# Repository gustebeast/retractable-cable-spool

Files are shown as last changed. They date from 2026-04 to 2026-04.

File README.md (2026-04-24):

# Retractable Cable Spool

A 3D-printable retractable cable spool driven by a constant-force spring, with a
ratchet to hold the cable out and a brake to control speed while retracting.

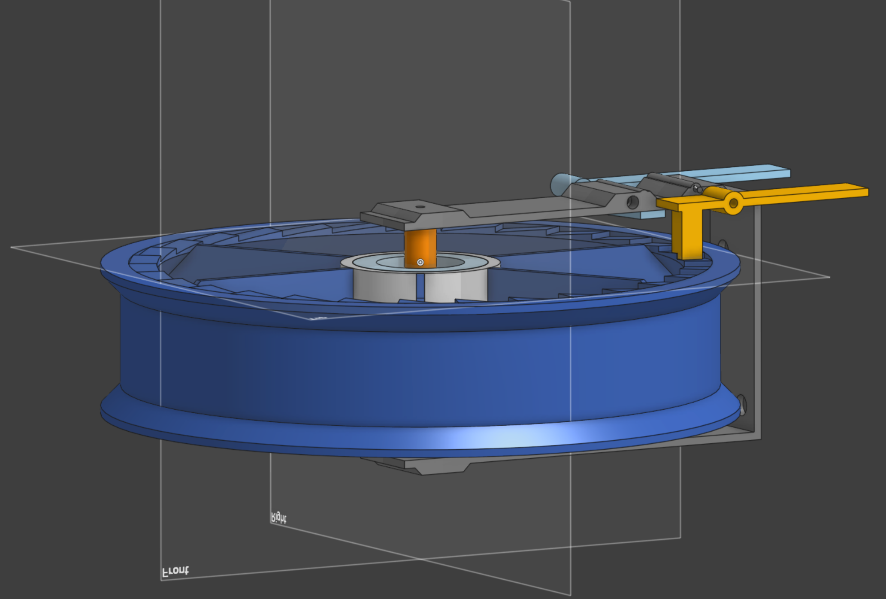
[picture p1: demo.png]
Assembly preview


## Source

All geometry lives in [`spool_flange.py`](spool_flange.py) — a single
[cadquery](https://cadquery.readthedocs.io/) script that generates every
printed part and the full assembly. The script was written collaboratively
with an LLM (Claude), which also handled the geometry math, the sourcing
research, and the assembly/printing documentation embedded in the module
docstring.

## Building

```bash
py -3.12 -m pip install cadquery
py -3.12 spool_flange.py
```

Running the script regenerates every STEP file in this directory:

- `spool_main_body.step` — spool with drum, flanges, ratchet teeth, brake ring
- `bearing_cap.step` — top bearing retainer
- `axle.step` — fixed center shaft with integrated spring stub
- `lever_housing.step` — U-bracket carrying both levers above the top flange
- `ratchet_lever.step`, `brake_lever.step` — the two actuating levers
- `brake_housing_pin.step` — small separately-printed stop pin (glues into the housing)
- `ratchet_spring.step`, `brake_spring.step` — visualization-only dummies of the purchased torsion springs
- `assembly.step` — everything in its as-built relative position, for dimensional verification

## Documentation

Everything you need to build one — purchased parts with SKUs and links,
sourcing plan, tuning constants, print orientation, and step-by-step
assembly — is in the module docstring at the top of
[`spool_flange.py`](spool_flange.py).

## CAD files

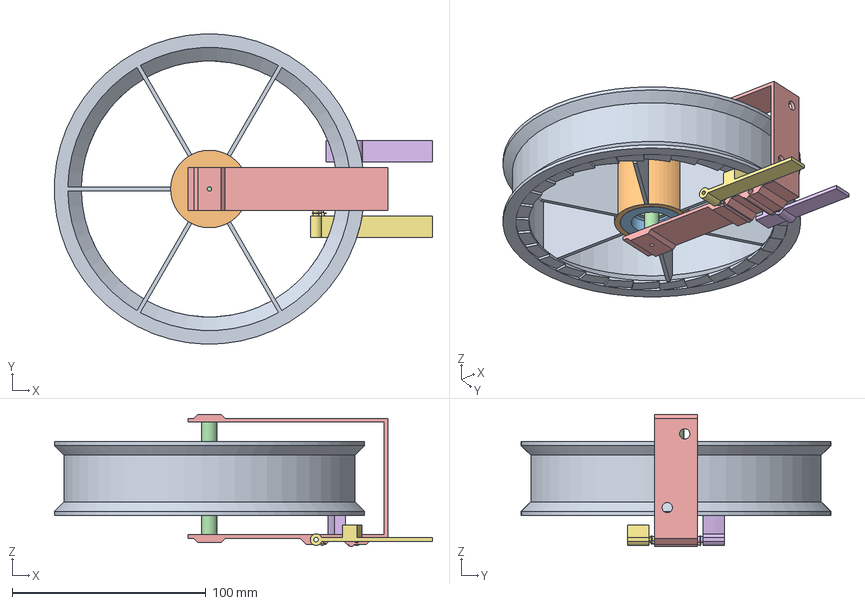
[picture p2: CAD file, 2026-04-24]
assembly.step
194.9 x 159.9 x 68.1 mm
main_body
bearing_cap
axle
lever_housing
ratchet_lever
brake_lever
ratchet_spring
brake_spring
brake_housing_pin

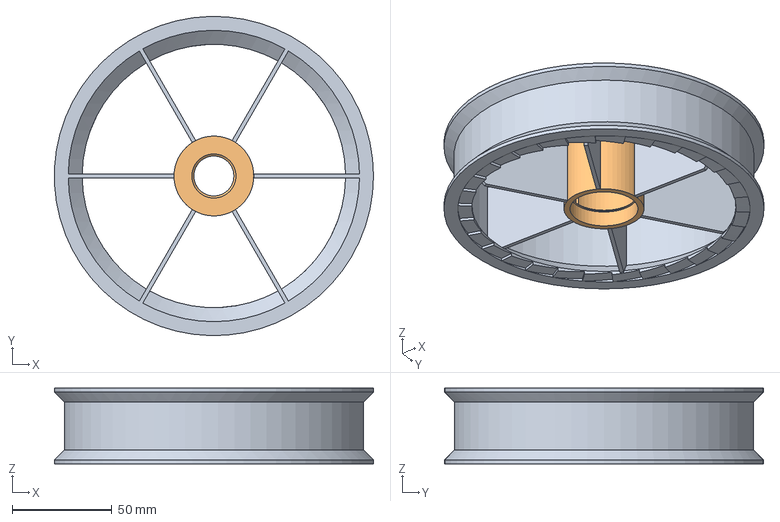
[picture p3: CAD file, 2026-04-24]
spool_main_body.step
159.9 x 159.9 x 38.0 mm

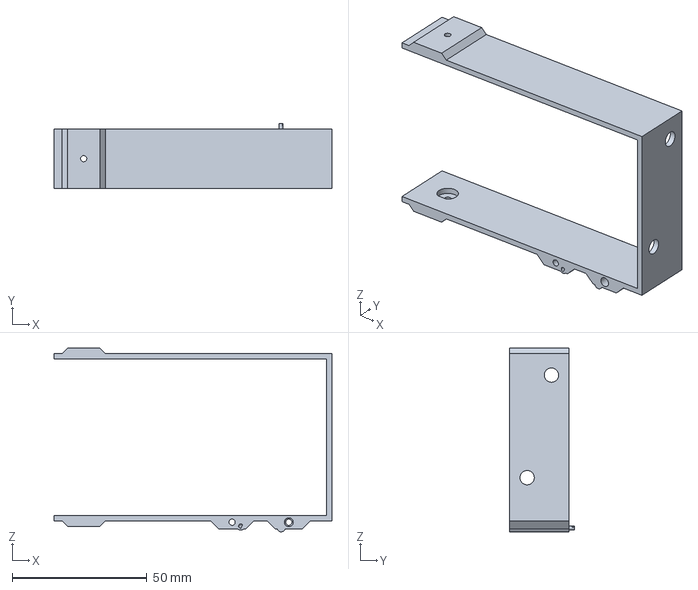
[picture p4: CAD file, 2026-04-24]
lever_housing.step
103.0 x 24.0 x 68.1 mm

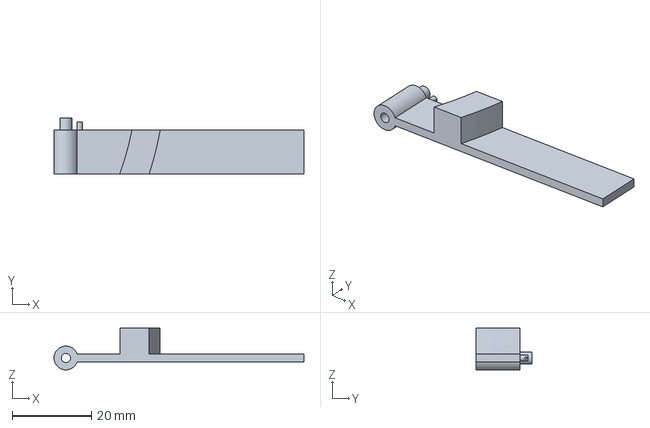
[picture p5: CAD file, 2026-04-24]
brake_lever.step
63.0 x 14.0 x 10.5 mm

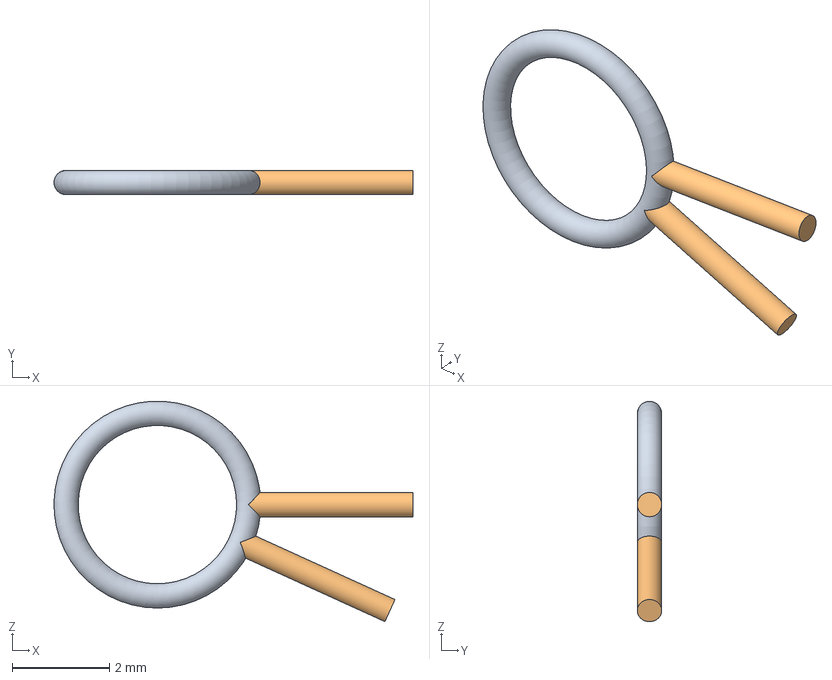
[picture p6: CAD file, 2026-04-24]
brake_spring.step
7.37 x 0.5 x 4.53 mm

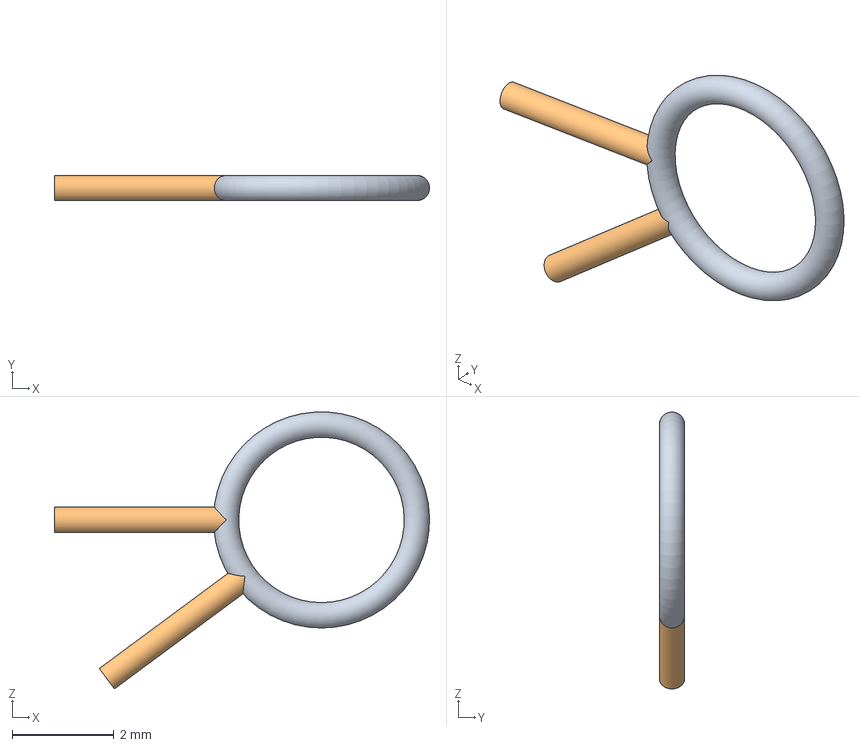
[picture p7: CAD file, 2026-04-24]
ratchet_spring.step
7.37 x 0.5 x 5.44 mm

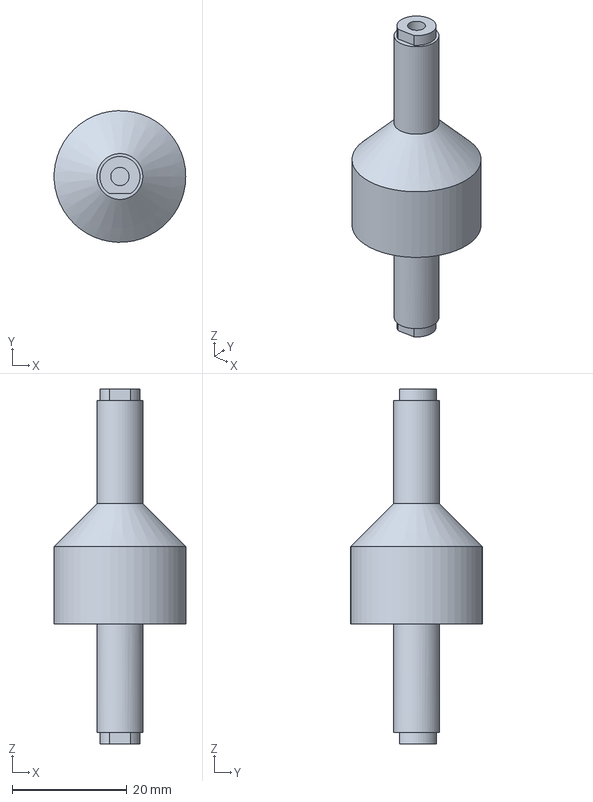
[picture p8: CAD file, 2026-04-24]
axle.step
23.0 x 23.0 x 62.0 mm

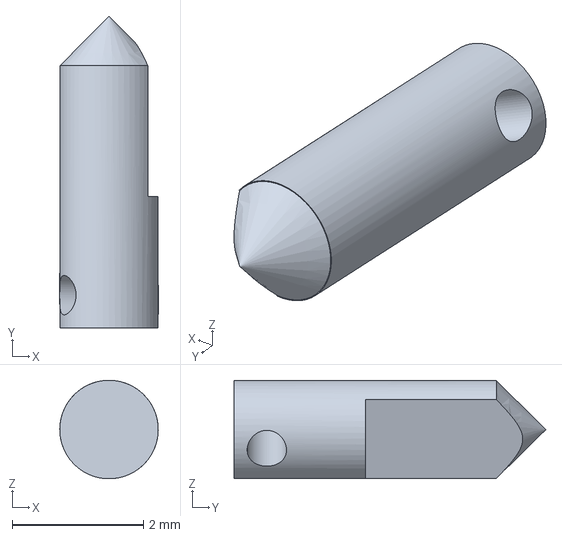
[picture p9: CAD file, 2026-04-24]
brake_housing_pin.step
1.50 x 4.75 x 1.50 mm

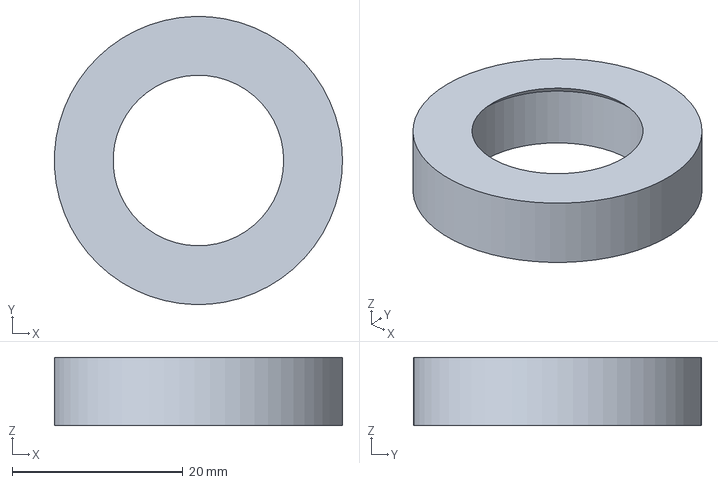
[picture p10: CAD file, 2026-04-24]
bearing_cap.step
33.8 x 33.8 x 8.00 mm

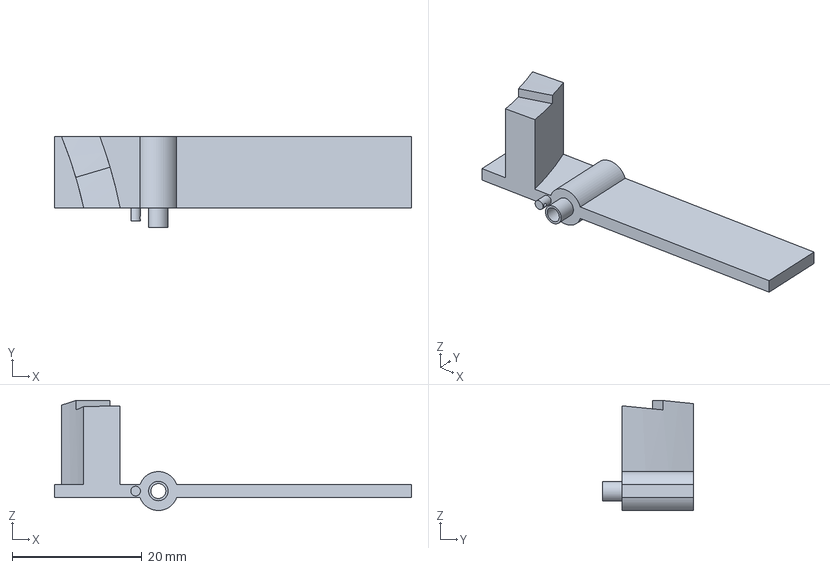
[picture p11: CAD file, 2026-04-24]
ratchet_lever.step
55.0 x 14.0 x 16.9 mm

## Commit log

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2026-04-25 Add source-cable pancake spool, wrap-around housing, and split bearing caps
    Major redesign to support a USB-C source cable that trades wraps with the
    main drum: pulling the retractable cable out unwinds the main drum and
    winds the source cable onto a small "pancake" spool integrated into the
    top bearing cap, so a single continuous cable runs from the wall outlet
    through the housing back panel, around the pancake, down through the
    spool interior, and out the drum OD — no slip ring required.
    Geometry changes:
    - Split bearing_cap into bearing_cap_top (with pancake spool) and
    bearing_cap_bottom (plain). Bearings now press in from the
    hub-cavity (interior) face of each cap.
    - 90° flat ret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
2026-05-07 Reorganize into src/, beef up housing, add cable transit through cap
    Major changes since the original monolithic spool_flange.py:
    - Modularize: split the build script into per-part modules under src/
    (dimensions, helpers, spool, caps, axle, housing, housing_guide,
    housing_pins, guide_axle, levers, viz, build). Cross-cutting concerns
    (cap key grooves, lever-dependent ratchet teeth, guide-bearing area)
    exposed as pure apply_to_*() functions called by build.py. Add a CLI
    --part NAME / --list to build a single part.
    - Geometry regression check: tools/check_geometry.py + tools/baseline.tsv
    detect accidental dimensional drift across refactors.
    - Structural beef-up: housing top/botto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
2026-05-07 Open-bottom-axle redesign: lever-side guide bearing + pancake removed
    - Eliminate pancake spool; source cable exits at lever-side axle bottom
    - Add lever-side 608 guide bearing between levers (rides on brake track)
    - Move RATCHET_PIVOT_X 76->70 to clear new bearing footprint
    - Move BRAKE_PIVOT_X 55->62 to preserve matched ROM ratio
    - Asymmetric housing trim: lever-side x_min=57, pancake-side x_min=-6
    - Remove back spine and lever-side cross-pin (no plate at x=0)
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2026-05-12 Drum: apply constant-thickness relief LAST, fixing the lost transit slot
    The groove-following relief leaves valid-but-fragile geometry that OCCT
    silently no-ops downstream booleans on (the cable-transit slot cut was
    vanishing, non-deterministically). Restructure: spool.py hands off the
    drum with the full-thickness wall (+cradle cut only); cap/lever cuts run
    on that robust geometry; build.py applies the relief last, after which
    nothing cuts main_body but the final heal. Lever cuts now remove the
    expected ~3164 mm^3 (was ~137 when the slot no-op'd).
    Also: spokes reach the cradle-bottom radius so they land flush on the
    relieved wall at each cradle crossing. Back guide axle TEMP at 2x length
    (u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
2026-05-12 Revert back guide axle to normal length (was 2x for update verification)
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2026-05-19 Checkpoint before lever pivot restructure (build #103)
    Captures current state of housing, levers, mount bracket, axle changes,
    and housing pin slab geometry before moving RATCHET_PIVOT_X and
    BRAKE_PIVOT_X to satisfy matched-ROM and pawl-clearance assertions.
2026-05-23 Checkpoint: remove guide axle/bearing + guide wheels (build #195)
    The -X housing extension is now a plain rectangular prism (no bearing
    pocket, no house-shape/M2 cut). Both guide wheels and the back-axle
    guide assembly are gone from the build, PARTS dict, assembly, and viz.
    Green at build #195. Checkpoint before the lever 90-degree rework
    (axial -> radial engagement, housing U -> L).
2026-05-23 Radial lever rework: L-housing, 90-deg levers, kinematic assertions (build #198)
    Levers rotated 90 deg to engage the rim's outer cylindrical bands radially:
    - Housing U -> L: vertical front-housing block on +X (carries both Y-axis
    M2 pivot screws) + pancake plate + plain -X extension. Front housing
    re-anchored to RIM_OD/2 + 5 mm (old SPOOL_CLEARANCE), not the stale
    FLANGE_OD.
    - Ratchet pivot above the teeth (z=17), brake pivot below the band (z=-3.5);
    both handles hang down and pull +x. Ratchet rest=engaged, brake rest=
    disengaged. Contacts are arc-conforming (pawl in the valley, pad on the
    band) with a viz rubber slab.
    - lever_kinematics.py rebuilt for radial engagement with loa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
2026-05-24 Polish radial levers + housing flush-mount/spring fixes (build #206)
    Lever shape/function:
    - Ratchet pawl now meshes with the actual rim teeth (carved with the rim
    ratchet band +/- backlash) instead of a smooth arc that fouled the tips —
    a true one-way catch (locks unwind, clicks the other way).
    - Handles are tapered rounded paddles (grip) instead of straight bars.
    - Rest-pose print-warp precomp set to 0 (radial levers print flat).
    Band swap + kinematics:
    - Swapped rims: ratchet teeth on the bottom (z=0..7), brake band on top
    (z=7..14), so the brake pivot lands ABOVE the spool bottom. Both pivots
    positive (ratchet 10, brake 3.5); lever hang -38 -> -19.
    - Kinematic assertions hold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
2026-06-11 Bands doubled (6mm ratchet + 6mm wheel), brake rim 11.6mm, pivot rework (build #484)
    - RATCHET_BAND_H 3->6 (teeth were skipping), pawl bump catch-face contact
    - Guide wheels 6mm tall; RATCHET_PIVOT_Z derived up to 16.1 to clear them
    - Brake band sized from pad needs (9 + 1 + 1.6 = 11.6mm), RIM_H 19.1
    - BRAKE_CONTACT_DELAY_DEG=3 handoff delay, pad rest gap 0.69 -> 1.72mm
    - M2 head recess in levers (spacers removed), 2.2mm self-tap bores in housing
    - Lever-housing gap 4.5 -> 3.3 (0.4mm spring spacers), pins auto-centered holes
    - Cable entry tunnel walled channel + z-cap, spring screw access hole
    - Spoke branching 48->24->12 (twist-extrude, ~45% material saving)
    - Retainer radial gap 2.5 -> 1.0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
2026-07-30 Commit to the modular redesign: promote v2/ to src/, delete v1
    The from-scratch modular design (spring-housing backbone + sliding
    stack) is THE spool now:
    - v2/*.py moved into src/; build is `py -3.12 -m src.build`, part STEPs
    export as src/<part>.step (no prefix), root viewer STEP unchanged.
    - v1 modules and archive/ deleted - git history is the reference. The
    four legacy modules the design still consumes survive: helpers,
    dimensions, caps, and axle_base (renamed from axle.py; the current
    axle extends its proven halves).
    - Every v1/v2 mention scrubbed from names, parts, outputs and comments.
    - Session work included: 2.4 ratchet teeth, GF depth-face joint
    clearances + quality hook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
2026-08-04 v3 axial redesign: rotating axle on a frame-pocketed 608, twist-lock spring anchor
    Archive the v2 modular design to v2/ and rebuild src/ around axial cable
    storage: the 608 sits IN the top frame and the axle rotates (spring
    arbor), separator fused to the bottom axle half, flat-spiral drum + lid
    on a rotational bayonet, fused bottom frame with spoked floor and center
    guide sleeve, bottom-608 spindle seat, ported v2 levers with the full
    kinematics assertion suite, and the spring strip now anchoring by a
    twist-lock window (teardrop neck hole + 45 degree insertion slot, no
    extra parts) in a wall under the +X arm. Build #837, overlap gate clean.
2026-08-04 Anchor window rework: tension-trap tent replaces the twist-lock cuts
    The teardrop+45-slot window still left an overhang at the slot's upper
    end cap (user catch). New shape per user's design: a tent window - flat
    top, 12-high side bays, 45 degree V floor to an 18.4 peak. The head
    enters flat-on at the tall middle (no twist), and the spring's
    one-signed tension parks the strip in a side bay too short for the head
    to escape. Symmetric so either spring handedness works. Every opening
    edge is vertical, 45 degrees, or a print floor. Build #838, gate clean.
2026-08-04 Bias the anchor window to the pinned spring chirality
    User pinned the rotation sense: pull-out spins the axle CW and tightens
    the spring, so the strip runs CCW going outward and its tension drags
    the anchored end toward -y. The symmetric tent becomes the original
    single-sided trapezoid: tall entry wall at +y (18.4 - head enters
    flat-on), one 45-degree floor climbing to the -y holding bay (12).
    Width forced at 6.4 by the 45-degree climb. Build #839, gate clean.
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2026-08-04 Flip frame_top upright: funnel bearing seat, mirrored window, flat-top joints
    frame_top now prints -z to +z (user's call), which reshapes everything
    orientation-dependent on it: the bearing seat becomes a 45-degree
    funnel cone (the flat lip step would overhang; the outer race chamfer
    lands face-on-face, 0.1 deep like the bottom seat); the anchor window
    z-mirrors (45-degree roof up to a dulled tip, stepped free bottom with
    a raised bay floor guarding the rotating lid below); and the anchor
    wall thickens to 2.4 by taking 0.8 from the flange clearance, outer
    face unmoved. The arc joints drop the arrowhead's angled top for a
    FLAT-TOP profile (both hosts print it fine now), and the separator/lid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
2026-08-04 Restore the +z-to--z window shape; funnel seat and flat-top joints stand
    Misread the flip: frame_top prints +z to -z (top face on the bed). The
    window returns to the #840 trapezoid - flat +z edge (prints as a
    floor), 45-degree floor down to the dulled one-bead tip (the roof of
    the hole as printed) - keeping the 2.4 wall on the 1.0 flange
    clearance. The funnel bearing seat is orientation-correct here too (a
    45-degree narrowing taper, upgrading the old accepted bridge-ring),
    and the flat-top arc joints + swapped sep/lid bayonet stand as-is:
    frame_top's cavities open at the print top with plain floors.
    Build #842, gate clean.
2026-08-04 Flush desk mount + per-side lever fork roofs
    MOUNT (v3 redesign, v2's validated wood screw verbatim): two identical
    brackets ride the +-Y arms - the rotating axle caps the centre so no
    full-length bar can cross flush, and flush is the point: assembled, the
    bracket tops sit level with the frame top face and the stack stays 10.4
    thick. Each bracket = mushroom tenon (new cadkit THROUGH-mortise site,
    both hosts print +z to -z) under a flush spine one stem wide, a shallow
    rail crossing the arc-joint zone in a 45-degree-V groove, and a screw
    pad in free air outboard of the arm tip. Both arms seat on one frame +y
    slide (cable pull preloads the seat; no lock insert, user's call);
    removal slides back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
2026-08-04 Close the wall band's bottom rim across the lever bays
    User catch (miscommunication resolved - wall_top's #834 C-ring stands):
    the bays' floor-up cut severed the fused band's bottom rim AND left the
    axial coil chamber open at both bays. The bay windows now start at the
    chamber ceiling (CH_TOP_Z): below it the band runs a closed ring again
    - bottom rim + coil containment - and every lever working part crosses
    the wall above it. Build #844, gate clean; posed probes (ratchet at the
    20-degree travel limit, brake + pad at contact) all 0.0000 against the
    restored band.
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2026-08-05 Mount rework: one-piece flush twist-lock ring
    Per the user's design review: the mount is now ONE continuous ring (no
    spacing error possible), its screws sit on quadrant pads INSIDE the
    frame footprint, and install is screw-first then offer-up + rotate ~9
    degrees to the stops - the same motion and angular constants as the
    frame_top<->frame_bottom arc joints. Rotation is what makes the
    one-piece geometry possible at all: the ring maps onto its own circle
    during install, so nothing sweeps across the axle. The ring sits at
    r 71.2 - the farthest bead radius out the arms whose THROUGH cavities
    keep a 1.6+ web to the frame arc joints (user: joinery near the beam
    ends, but clear of the top<->bottom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
2026-08-05 45-degree hand ports through the fork-side blocks at both bays
    User: the web/column corner still pinched hand access to the levers.
    Each bay gets a port cut through the web + column + pad along Y: inner
    edge ON the wall bottom's OD (user's datum), vertical sides, and a
    single-pitch 45-degree roof rising toward the wall - printable upright.
    The column keeps a full-height foot leg outboard of the port and the
    web's wall-continuation inboard of the OD is untouched. Per-side eaves:
    ratchet to the chamber ceiling; brake stops 0.8 under its low pivot
    boss, with the roof-tangent (R*sqrt2) term since a 45-degree roof binds
    at the circle's tangent point, not its bottom. Build #849, gate clean.
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2026-08-05 Mount refinement: pads are the stop, 51% arm intact, full-depth tenons
    Three user passes: (1) screw pads at ZERO gap - seated, each pad lands
    flat on its arm's flank, making the pads the seating stop; the arc
    joints keep their 0.15 seat clearance and never bottom (pad azimuth
    now derived exactly, screws +-10.65 off-axis - the beam just needs to
    span both screws of a pair). (2) joint width 6.4 -> 4.8: the cavities
    now leave 51% of the arm's width intact (asserted >= 49%). (3) tenons
    grown to fill the through cavities (cadkit tenon_arc height override,
    canonical synced): tips one bead above the arms' undersides, hovering
    over the spring-flange plane at the inner ring. Build #858, gate
    clean; p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
2026-08-05 Mount joint trimmed from the stop side: 50/50 tenon vs arm
    User: the tenon should fill its mortise, and the mortise should take
    no more of the arm than needed - reduce from the stop side. The tenon
    now ANCHORS AT THE ARM'S ENTRY FACE and spans MOUNT_TEN_ARC = half the
    crossing (5.2 arc-mm) inboard; the cavity is exactly tenon + seat +
    entry overshoot, so the stop-side HALF of every crossing is solid arm
    (5.1mm, was a 1.6 stop wall). Install twist drops to ~11.1 deg.
    Build #861, gate clean; probes: engaged 5.2 / solid 5.1 per crossing
    on both rings, frame_top intersect 0.0000 across the rotation.
2026-08-05 Frame arc joints adopt the mount rings 50/50 scheme
    User: copy the mount joint's clearance figures to the bottom<->top
    frame joint. The frame arc tenons now anchor at their arm's entry face
    and span half the crossing; the cavities are exactly tenon + seat +
    entry overshoot, leaving the stop-side half of each arm crossing solid
    (TOP_STOP_WALL retired - the stop wall is wherever the cavity ends).
    Build #862, gate clean; probes: seated 0.0000, install path clear
    through -25 deg, stop direction binds immediately as designed.
2026-08-05 Revert the frame arc-joint 50/50 change (user: misunderstanding) - frame_top/frame_bottom joints back to centered tenons + TOP_STOP_WALL; mount rings keep their #861 scheme. Rebuilt as #862, gate cle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
2026-08-05 Mount joint gets the frame joints depth-face clearance; frame arc tenons run flush to the entry face - (1) user: copy the z-clearance figures from frame_top/frame_bottom to frame_top/mount: the mushr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
2026-08-05 Open exit-port top; octagon Z-relief on mount joint; 50 percent rule + shared cadkit crossing for both ring joints [build 866]
    Wall: the exit-port sawtooth ceiling is retired (user: unnecessary overhang) - the port cuts open through the band top rim over its ~30 deg span; CABLE_EXIT_TEETH and its assert removed.
    Mount joint: cadkit octagon now carries the 0.30 z-relief via the user mechanism (mortise waist vertical +0.30, tenon stem +0.30 - the stop sign rides down to fill it), so separating frame from mount rides 0.30 before the flare faces engage. Arm floor under the deeper cavities: 1.63 (>= 1.6 asserted).
    Frame joint: the 50 percent rule applies here after all (user reversed the earlie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
2026-08-05 Flip both rotational joints so sustained loads preload the stops [build 867]
    Chirality audit (user worry: rotational joinery working undone over time). With the as-built hand, every sustained load pointed at the ENTRY: parked, the spring torque loop reacts CW on frame_top (strip anchor at +X pulled -Y) and CCW on frame_bottom (ratchet pawl holding the separator) - the unseating relative twist across the frame joint; pull-out torques the whole assembly CW (cable line of action is tangent on the drum CW-driving side) - the mount joint uninstall direction; retraction brake drag matched.
    Fix: cadkit ArcCrossing gained a hand parameter (canonical d4f4923); both crossings flipped to hand=ccw. fra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
2026-08-05 Open-ended axle slits (slide onto the fixed strip) + fix the open-shell artifact Bambu flagged [build 873]
    Axle slits: the closed-window design assumed the spring strip could thread through - it cannot (the strip is fixed). Reverted to v2: each half slit is fully open at its joint-side end and the halves slide onto the strip - separator open through its +z column top (mortise mouth splits into two C-halves), axle_top open through its tenon bottom. The strip starts 4mm in from the spring edges (user), so the closed ends land just past the strip zone: STRIP_Z0/Z1 = spring edges -/+ 4, SLIT_Z_CLR 1.0. axle_top keeps a solid shaft above the strip zone (through the bearing); the separator keeps s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
2026-08-05 Tenon tip lands at the strip start - 4 (not 5) above the spring bottom [build 874]
    User catch: axle_top ended 5mm +z of the spring bottom. JOINT_Z0 was JOINT_Z1 - a fixed 23; now JOINT_Z0 = STRIP_Z0 (spring bottom + 4, the strip lower end) and JOINT_H derives as 24 - the tenon reaches exactly the strip start, one more mm of glue engagement. Separator top confirmed right at 4 below the spring top (MORTISE_TOP_GAP, unchanged). Gate + shell audit clean.
2026-08-05 Axle slits end 3.2 in from the spring edges - 0.8 shrinkage margin past the strip [build 876]
    User sequence: the 1.0 slit margin cost too much section (separator slit ran below the axle_top tip; axle_top slit above the separator top); exactly-4 left no shrinkage room; 3.2 is the balance. SLIT_INSET 3.2 -> SLIT_ZLO -28.8 (separator floor) / SLIT_ZHI -3.2 (axle_top ceiling); tenon tip stays at the strip start (-28, JOINT_Z0 = STRIP_Z0). End planes probe-verified; gate + shell audit clean.
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2026-08-06 Swap axle mortise/tenon for the upside-down spring; tighten + lengthen the lid bayonet [build 878]
    User: the spring installs upside down in v3 (the axle spins instead of being fixed, flipping the wind chirality), so the big 13.4 flange hole is on TOP: the mortise collar moves to axle_top (lip - shaft - 45 cone inside the top hole zone - 11.45 collar with the bore and open-bottom slit) and the separator carries the tenon (base column + root cone topping at a new SHOULDER 0.5 under the spring, then the 7.95 post through the 8.7 bottom hole to the top datum). Outer envelopes unchanged (-28.8/-3.2 datums hold); spring dummy mirrored (big bore now cut from the top); SPRING_BORE values + all flang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
2026-08-06 Big batch: headless 8.0 axles, 2.4 floor, aggressive brake stop, snug beam-aligned anchor window, ratchet over-pull wing+shelf at 20 deg, mount 2.4 squares + guide tails, pocketed separator [builds 8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
    axle_top: retention head REMOVED (user: with the collar at the bottom there was no installable direction through the bearing; installs from below, stack weight rides the bottom 608). Both bearing shafts 7.95 -> 8.0 (user: a touch loose); STUB_BOSS_D independent 11.2. Floor webbing 1.6 -> 2.4 z and width (user: z-flex under centre pressure).
    Brake rest stop: BRAKE_STOP_GAP -0.25 interference at plumb (user: the 0.15-gap print never touched; TPU squish), reach 2.5; gate whitelists pad/fram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
2026-08-06 Cable 3.85, capacity 1 m - and the frame radii now DERIVE [builds 883-884]
    CABLE_D 3.0 -> 3.85 (user) and CABLE_CAPACITY 6 ft -> 1 m (user). The resize surfaced hardware floors: the rim is now FLOORED by the 13 connector pass tunnel (coil-derived OD would pinch it into the tooth band at 1 m - the disk keeps the minimum and carries spare coil room) and the chamber depth by the entry-port gable; the guide sleeve slimmed to 26.4 for the fatter cable tight coil; the ratchet wing inner edge is rim-derived (a hard-coded 69.5 broke on resize).
    FRAMEJ_R, MOUNT_RING_R and MOUNT_RING2_R were pinned bead radii sized to the 6-ft frame; they now DERIVE (snapped to the bead grid, honoring their recorded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
2026-08-06 Ratchet wing to the -y side (print top); brake stop corbel gets a one-bead end face [build 886]
    User: the ratchet lever prints - to + y, so the over-pull nub must TOP the print - moved from the +y outer strip to the -y inner strip (window edge 5.2 .. lever face 7, equally handle-free), and the shelf now roots on the +X beam flank instead of the column (welded across its whole width; weld asserts updated).
    User: the brake rest-stop corbel ran to a knife point - its 45 underside now ends on a vertical one-bead (0.8) face, shortening the -y reach to TOP_T - 0.8 past the contact plane; BRAKE_STOP_TIP_OVER retired.
    Gate + shell audit clean; full probe suite passes (ratchet clear -19..+14, parks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
2026-08-06 Cable horn pier corrected: straight along +x to the fork-block plane [build 890]
    User: the pier was angled (radial at 45) and short - it now runs x-parallel from the exit window midway point out to the part +x edge (FRAME_R_OUT), root trimmed to the band bore (nothing intrudes into the coil chamber; the below-sill band ring is the weld). Top still flush with the window bottom. Gate + shell audit clean.
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2026-08-06 Design order fixed: window from cable geometry alone, horn rides its midway point [build 900]
    User: the horn is not a factor in the window - design order is window first, horn second. The window derivation already used only coil geometry (parallel-exit band); HORN_YC now derives as the finished windows midpoint (58.78, the original midway-point spec restored - was frozen at the historical 49.74 line). The pier, guide and mouth flares all followed. Gate + shell audit clean.
2026-08-06 Horn pier x-start parametric on the bore chord at its far-y edge [build 901]
    User: the pier stopped short of the drum on its +y side after the horn moved to the window midpoint - the hardcoded x-start (44) predated the move. It now derives from the band bore chord at the pier far-y edge minus 1, and the bore-cylinder cut trims the root as before, so the pier welds through the below-sill band ring across its full width at any horn position. Gate + shell audit clean.
2026-08-06 Horn redesign: tunnel block with exit bell + entry chamfer [build 903]
    User: design the IDEAL cable model first, printability/installation aside. The open-top guide walls and the roof-cap plan are DROPPED; the pier stays and a second prism sits on it at the +x end, shaped by three cuts: (1) a round 6.4 through-tunnel along x, floor tangent to the pier top (no step for the cable); (2) a full-circle quarter-round exit bell (r 1.6) revolved around the bore axis at the +x face - the free cable pulls in any direction without biting an edge, scooping into the pier top below; (3) a horizontal-only 45-degree entry chamfer (1.6 each side) - inside, the cable is locked to the spool plane, only its in-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
2026-08-06 Horn cap attachment: mushroom rails + trailing stop flange [build 906]
    User: cadkit joinery, install sliding - to + y, frame prints up / cap prints inverted -> the flat-top MUSHROOM (up+down combo). Two rails at +/-2.8 off the block x middle, width 3.2: four tenon segments (2.4 engagement each) rise off the trough strips tops, rooted 1.0 into the pier; the cap takes a through-cavity per rail across its width, open at the +y face for entry, relieved 0.3 past the far face so the STOP defines seating. The stop: extra material on the CAP only (bottom prism unchanged, user) - a 2.4 flange at the trailing -y end, hanging 2.4 below the equator, landing on the troughs -y face to block +y over-travel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
